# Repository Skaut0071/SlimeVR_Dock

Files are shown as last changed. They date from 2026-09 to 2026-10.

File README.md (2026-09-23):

# SlimeVR\_Dock

Continuation of the tracker project: https://github.com/Skaut0071/SlimeVR_Tracker

This repository contains a smart (overengineered) charging dock station for my previously designed SlimeVR FBT trackers.

The dock is built around an ESP32-C3, which controls the charging system and provides protection logic for connected trackers if a fault condition occurs.

## Features

* 8 USB-C charging ports (J2-J9), arranged as 4 dual-port channels
* Powered from a single USB-C PD input (20V / 3A, negotiated by a CH224K), stepped down to 5V (up to 8.5A) for the ports
* Per-port voltage/current monitoring with an INA226 (8x) over I2C
* Overcurrent protection and per-channel enable/fault handling with an AP22652 load switch (4x)
* Temperature/humidity monitoring (BME280 module on the I2C header)
* 4-pin PWM fan header with tachometer input, driven by the ESP32-C3
* Audible error alerts through an on-board buzzer
* Wireless connectivity over Wi-Fi

## Hardware overview

| Block | Main parts | Notes |
| --- | --- | --- |
| MCU | ESP32-C3-WROOM-02 (U1) | Controls charging, reads monitors, handles faults |
| Power input | USB-C receptacle (J1\_MainPW1), CH224K (U2), NDT452AP (Q1) | Requests 20V from a PD source |
| 5V step-down | TPS548A20 (U4), 2.2uH inductor (L1) | 20V to 5V, 8.5A |
| 3V3 regulator | XC6220B331MR (U3) | Powers the ESP32-C3 and logic |
| Charging channels (x4) | 2x USB-C, 2x INA226, AP22652 load switch, BC857 | Each channel serves two ports; see schematic sheet below |
| I/O expansion | 2x 74HC165 (U17, U18), 74HC595 (U19) | Shift registers for reading channel status and sending control signals |
| Headers | Control, Monitor, Prog (3-pin), Temp (4-pin), Fan (4-pin) | Dev/debug access, sensor and fan connectors |
| Buzzer | BZ1 | Error alerts |

The board is a 2-layer, 1.6mm PCB, roughly 100 x 78 mm (JLCPCB gerbers included).

## Schematic structure

The design is hierarchical (KiCad):

| Sheet | File | Description |
| --- | --- | --- |
| Root - SlimeVR Dock (rev 3.1) | `Board/SlimeVR_Dock.kicad_sch` | MCU, PD input, 3V3 regulator, shift registers, connectors, buzzer |
| 20V to 5V 8.5A Stepdown (rev 2.1) | `Board/StepDown.kicad_sch` | TPS548A20 buck converter |
| Dual USB-C charger monitoring (rev 1.8) | `Board/DUSBSS.kicad_sch` | Instantiated 4x; load switch, protection and detection for a pair of ports |
| Overcurrent protection (rev 1.2) | `Board/USB-C.kicad_sch` | USB-C connector with INA226 current measurement, instantiated 2x per channel |

The PCB is currently at rev 5 (`Board/SlimeVR_Dock.kicad_pcb`).

## Firmware flashing note

To flash new firmware versions, you must use the internal programming pins (`Prog` header).
Or in future, firmware flashing over web interface of the device.

USB-C cannot be used for flashing in this design, because the same USB connection is used to power the board.

## Repository layout

* `Board/` - KiCad project (schematics, PCB, custom footprints in `Library.pretty`)
* `Gerb/` - Gerber/fabrication files for JLCPCB
* `PDF/` - PDF schematic, BOM (CSV) and interactive BOM
* `3D/` - 3D model exports

## Interactive BOM

* [Interactive BOM](https://skaut0071.github.io/SlimeVR_Dock/PDF/ibom.html)

## PDF Schematic

* [PDF Schematic](https://skaut0071.github.io/SlimeVR_Dock/PDF/SlimeVR_Dock.pdf)

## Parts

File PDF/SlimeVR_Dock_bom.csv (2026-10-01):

Reference | Qty | Value | Footprint | # | LCSC
C27 | 1 | 470pF | Capacitor_SMD:C_0805_2012Metric | 1 | C1743
C11,C13 | 2 | 1nF | Capacitor_SMD:C_0603_1608Metric | 2 | alr C100040
C42 | 1 | 2.2nF | Capacitor_SMD:C_0402_1005Metric | 3 | C1531
C14,C15,C16,C17,C18,C19,C20,C21,C28,C32,C33,C34,C35,C36,C37,C38,C43,C44,C45,C46 | 20 | 100nF | Capacitor_SMD:C_0603_1608Metric | 4 | alr C6119867
C39,C41 | 2 | 100nF | Capacitor_SMD:C_0805_2012Metric | 5 | alr C49678
C1,C40,C47 | 3 | 1uF | Capacitor_SMD:C_0603_1608Metric | 6 | alr C15849
L1 | 1 | 2.2uH | Library:L_Coilank_APS0730 | 7 | C49261221
C29 | 1 | 4.7uF | Capacitor_SMD:C_0805_2012Metric | 8 | alr C98192
C2,C3,C4,C5,C6,C7,C8,C9,C10,C12 | 10 | 10uF | Capacitor_SMD:C_0603_1608Metric | 9 | alr C19702
C22,C23,C30 | 3 | 10uF | Capacitor_SMD:C_1210_3225Metric | 10 | alr C47117451
C24,C25,C26,C31 | 4 | 47uF | Capacitor_SMD:C_0805_2012Metric | 11 | alr C16780
R25,R26,R27,R28,R29,R30,R31,R32 | 8 | 50m | Resistor_SMD:R_0805_2012Metric | 12 | C42389461
R55 | 1 | 2R2 | Resistor_SMD:R_0603_1608Metric | 13 | C2907006
R54 | 1 | 3R | Resistor_SMD:R_0805_2012Metric | 14 | C17660
D2 | 1 | 10V | Diode_SMD:D_SOD-123 | 15 | alr C47117498
R1 | 1 | 1k | Resistor_SMD:R_2010_5025Metric | 16 | C2974087
R33 | 1 | 1k | Resistor_SMD:R_0603_1608Metric | 17 | alr C22548
R23,R24 | 2 | 4.7k | Resistor_SMD:R_0603_1608Metric | 18 | alr C99782
R2,R3,R4,R5,R7,R8,R10,R11,R13,R14,R16,R17,R18,R19,R20,R21,R22,R35,R38,R42,R43,R44,R45,R46,R47,R48,R49,R51,R52,R53,R57,R58,R59,R60,R61,R62 | 36 | 10k | Resistor_SMD:R_0603_1608Metric | 19 | alr C98220
R6,R9,R12,R15 | 4 | 13k | Resistor_SMD:R_0603_1608Metric | 20 | C54920854
R36 | 1 | 20k | Resistor_SMD:R_0603_1608Metric | 21 | C2907011
R39 | 1 | 36k | Resistor_SMD:R_0603_1608Metric | 22 | C54531400
R34,R37,R41 | 3 | 75k | Resistor_SMD:R_0603_1608Metric | 23 | alr C2907067
R56 | 1 | 100k | Resistor_SMD:R_0603_1608Metric | 24 | alr C14675
R40 | 1 | 240k | Resistor_SMD:R_0603_1608Metric | 25 | alr C4197
D1 | 1 | 1N4007WS | Diode_SMD:D_SOD-323 | 26 | alr C7473299
U17,U18 | 2 | 74HC165 | Package_SO:SOIC-16_3.9x9.9mm_P1.27mm | 27 | alr C5613
U19 | 1 | 74HC595 | Package_SO:SOIC-16_3.9x9.9mm_P1.27mm | 28 | alr C5947
U5,U8,U11,U14 | 4 | AP22652W6-7 | Library:SOIC_52W6-7_DIO | 29 | alr C2158038
Q6 | 1 | BC817 | Package_TO_SOT_SMD:SOT-23 | 30 | alr C39828
Q2,Q3,Q4,Q5 | 4 | BC857 | Package_TO_SOT_SMD:SOT-23 | 31 | alr C111644
BZ1 | 1 | Buzzer | Buzzer_Beeper:Buzzer_12x9.5RM7.6 | 32 | alr - Any passive buzzer
U2 | 1 | CH224K | Package_SO:SSOP-10-1EP_3.9x4.9mm_P1mm_EP2.1x3.3mm | 33 | alr C970725
J1_Control1,J1_Monitor1,J1_Prog1 | 3 | Conn_01x03_Pin | Connector_PinHeader_2.54mm:PinHeader_1x03_P2.54mm_Vertical | 34 | x - Only holes
J1Fan1 | 1 | Conn_01x04_Pin | Connector:FanPinHeader_1x04_P2.54mm_Vertical | 35 | alr C240840
J1Temp1 | 1 | Conn_01x04_Pin | Connector_PinHeader_2.54mm:PinHeader_1x04_P2.54mm_Vertical | 36 | x - Only holes
U1 | 1 | ESP32-C3-WROOM-02 | RF_Module:ESP32-C3-WROOM-02 | 37 | C2934560
U6,U7,U9,U10,U12,U13,U15,U16 | 8 | INA226 | Package_SO:VSSOP-10_3x3mm_P0.5mm | 38 | alr C49851
Q1 | 1 | NDT452AP | Package_TO_SOT_SMD:SOT-223 | 39 | alr C274614
U4 | 1 | TPS548A20RVER | Library:RVE0028A | 40 | alr C468255
J1_MainPW1 | 1 | USB_C_Receptacle_USB2.0_16P | Connector_USB:USB_C_Receptacle_GCT_USB4105-xx-A_16P_TopMnt_Horizontal | 41 | alr C5178539
J2,J3,J4,J5,J6,J7,J8,J9 | 8 | USB_C_Receptacle_USB2.0_16P | Library:YTC-TC16S-128 | 42 | alr C2927282
U3 | 1 | XC6220B331MR | Package_TO_SOT_SMD:SOT-23-5 | 43 | alr C86534

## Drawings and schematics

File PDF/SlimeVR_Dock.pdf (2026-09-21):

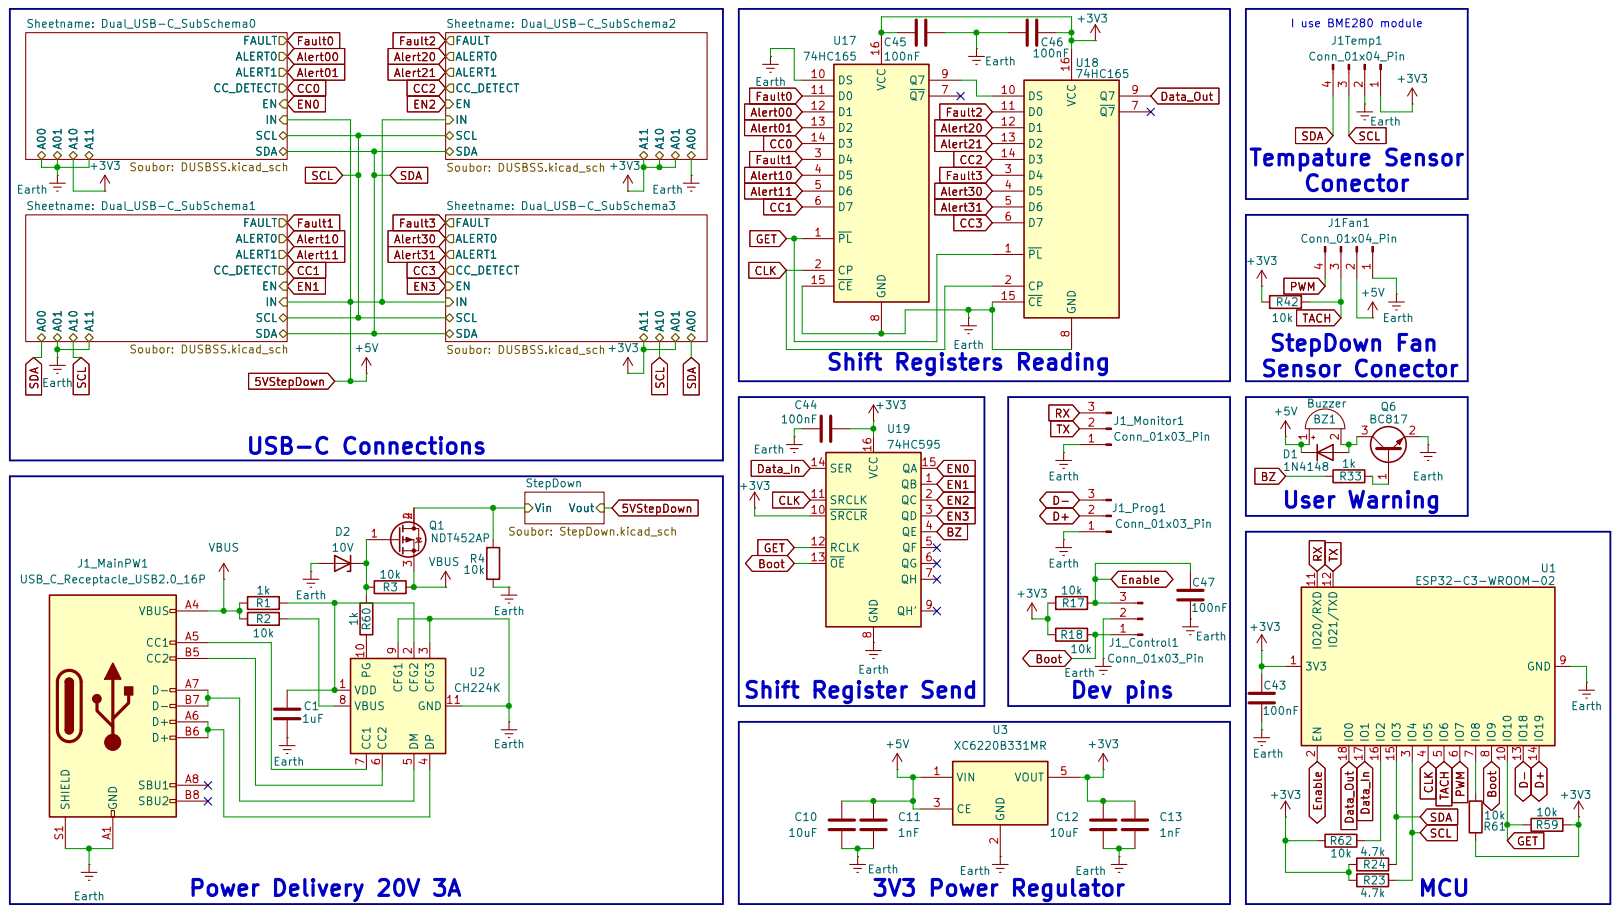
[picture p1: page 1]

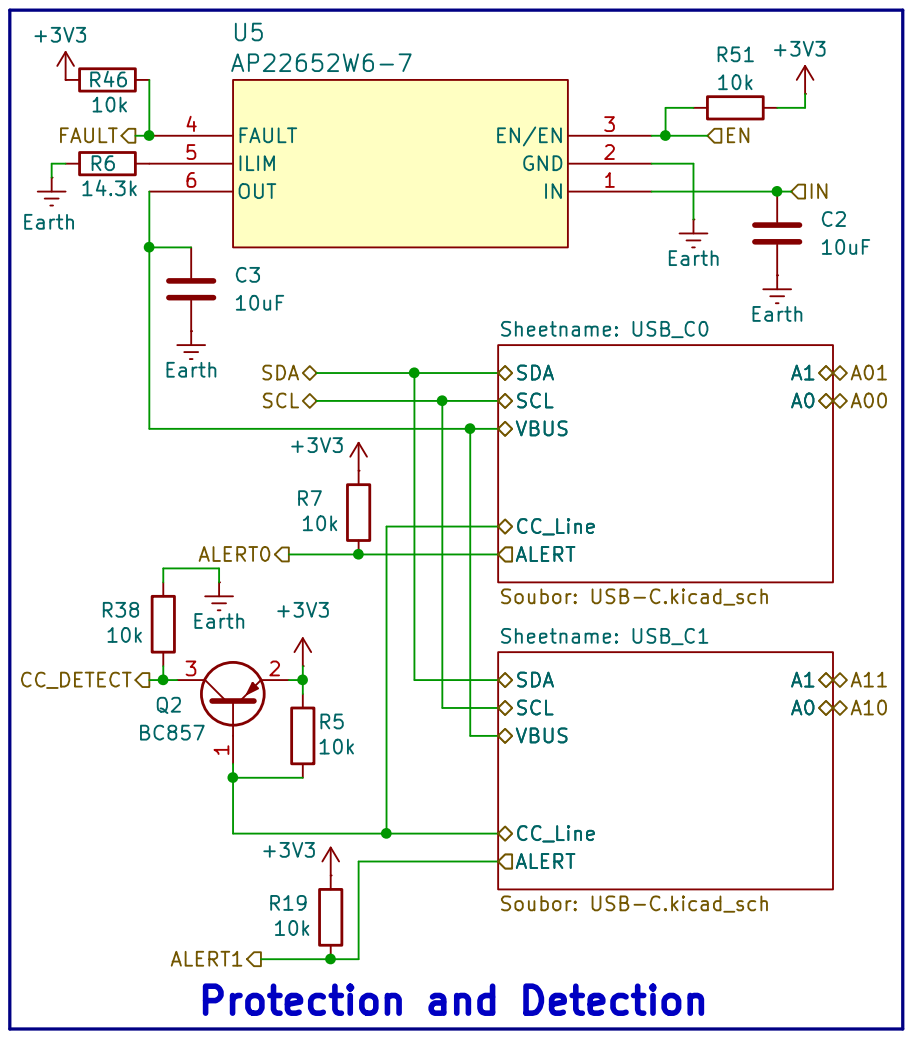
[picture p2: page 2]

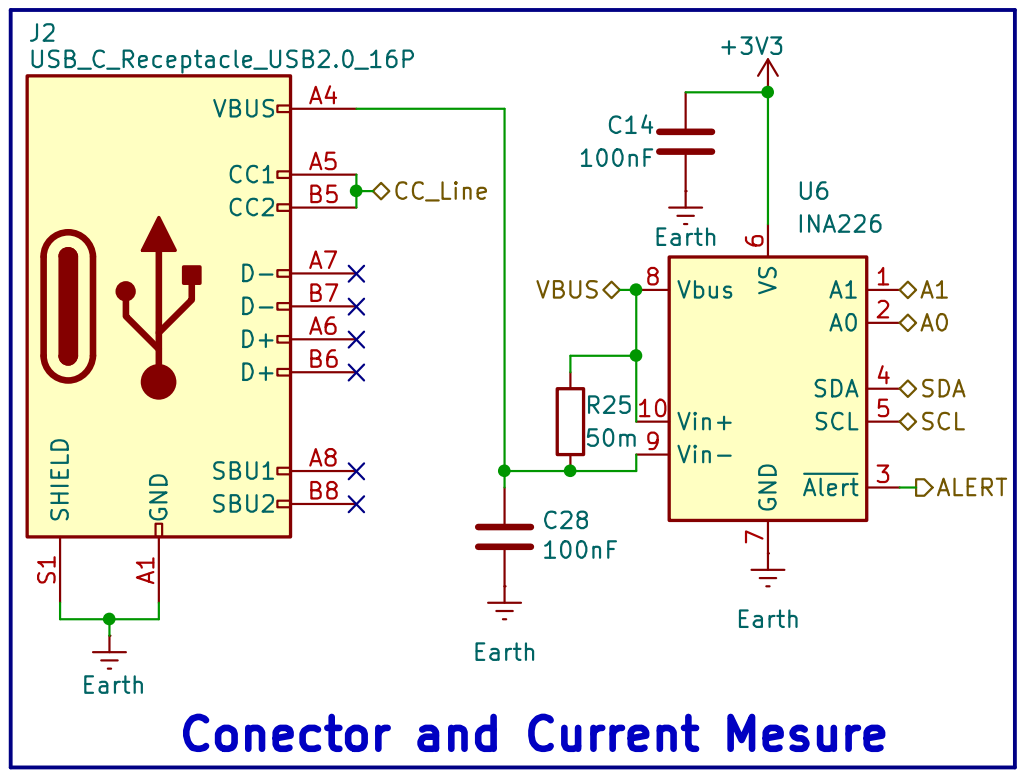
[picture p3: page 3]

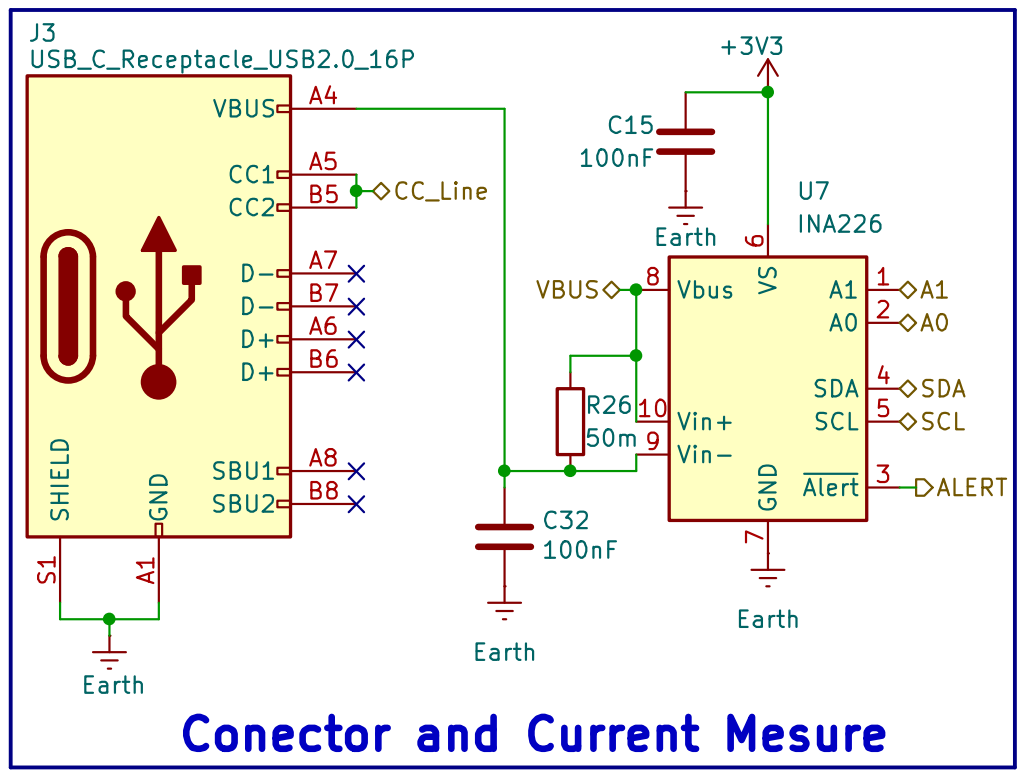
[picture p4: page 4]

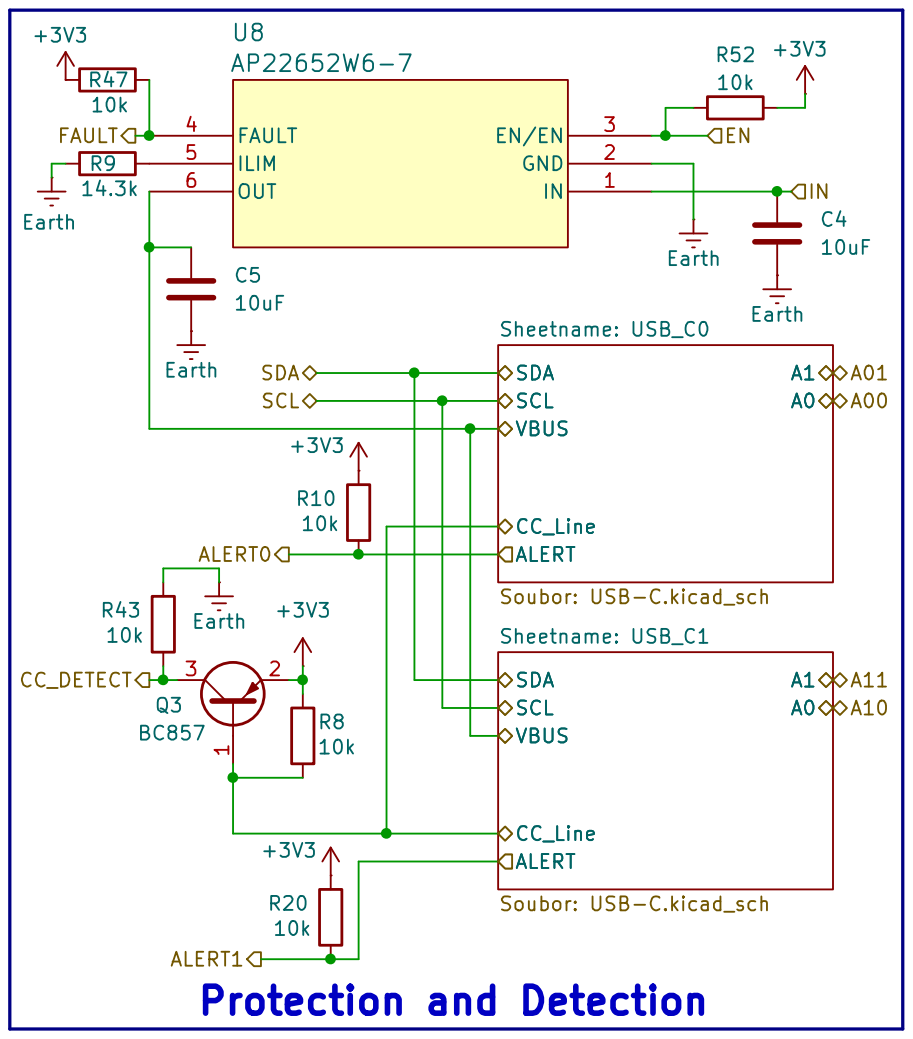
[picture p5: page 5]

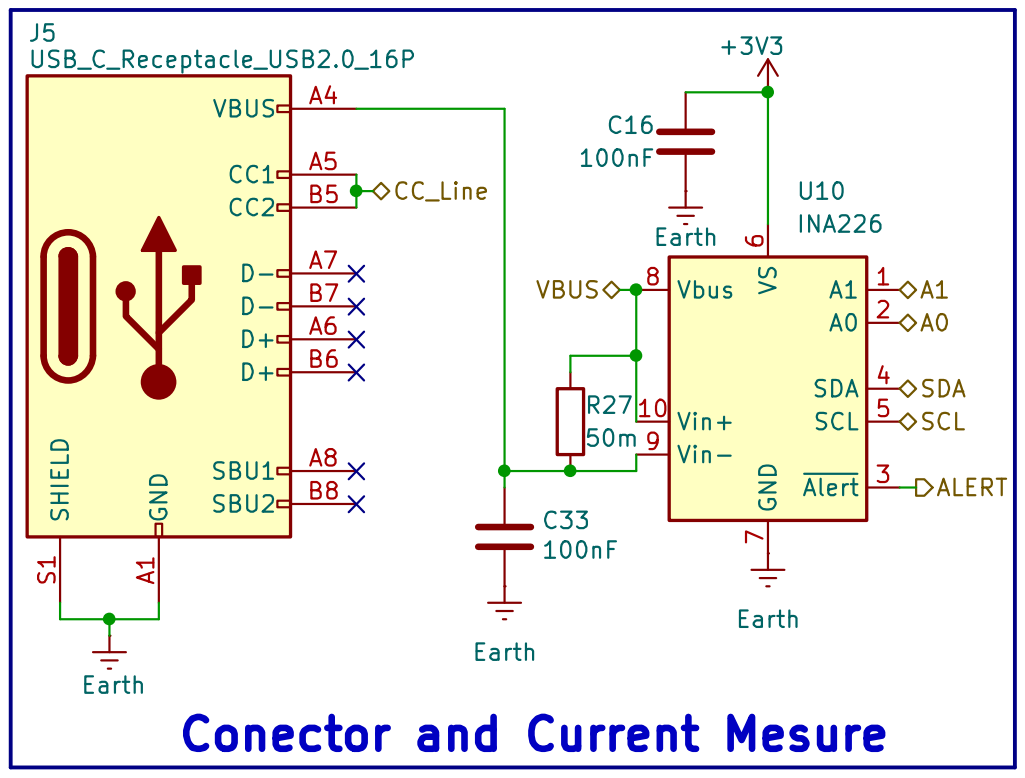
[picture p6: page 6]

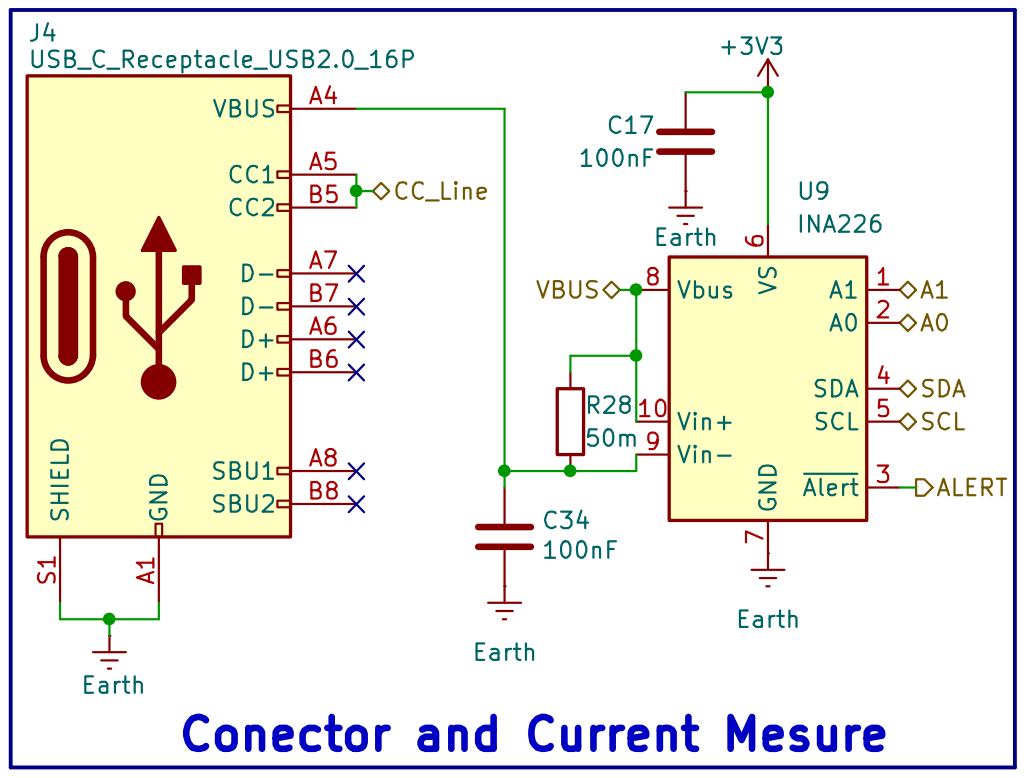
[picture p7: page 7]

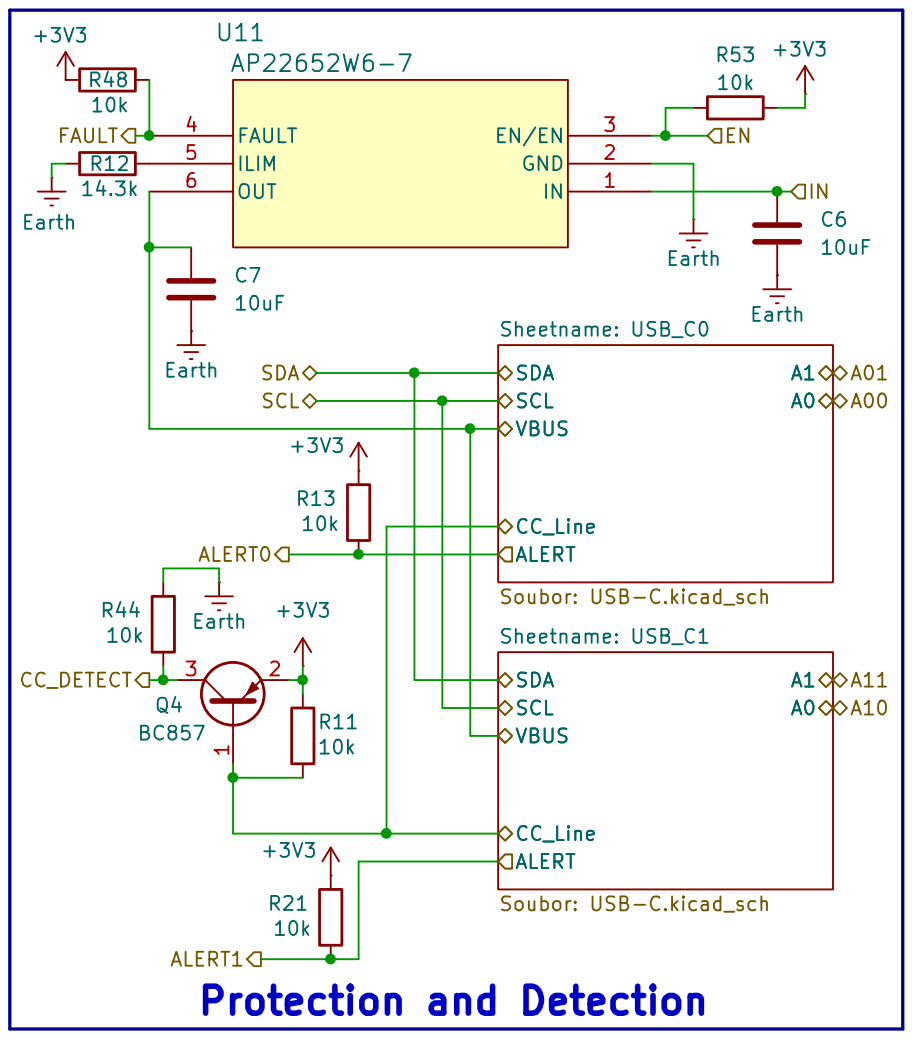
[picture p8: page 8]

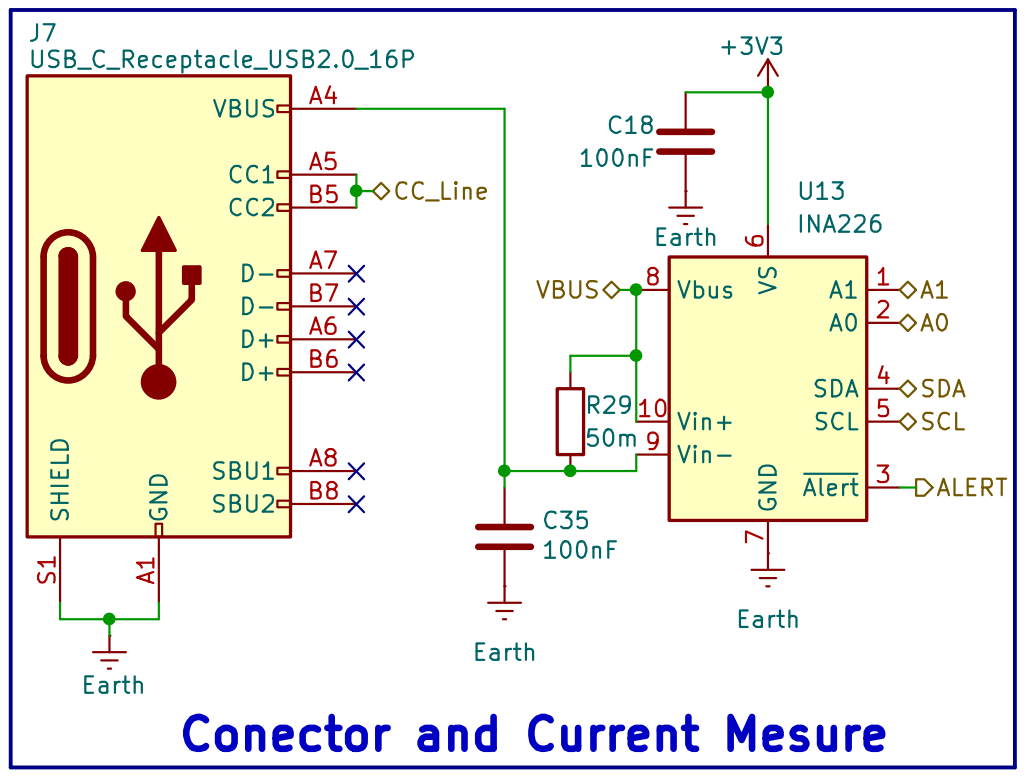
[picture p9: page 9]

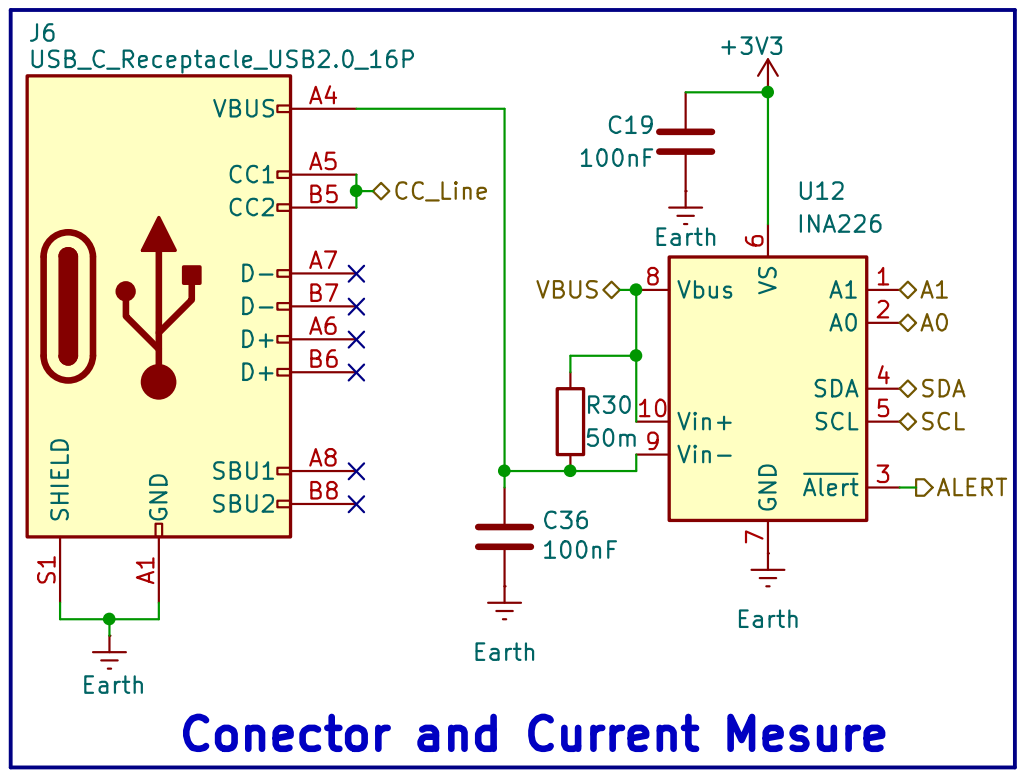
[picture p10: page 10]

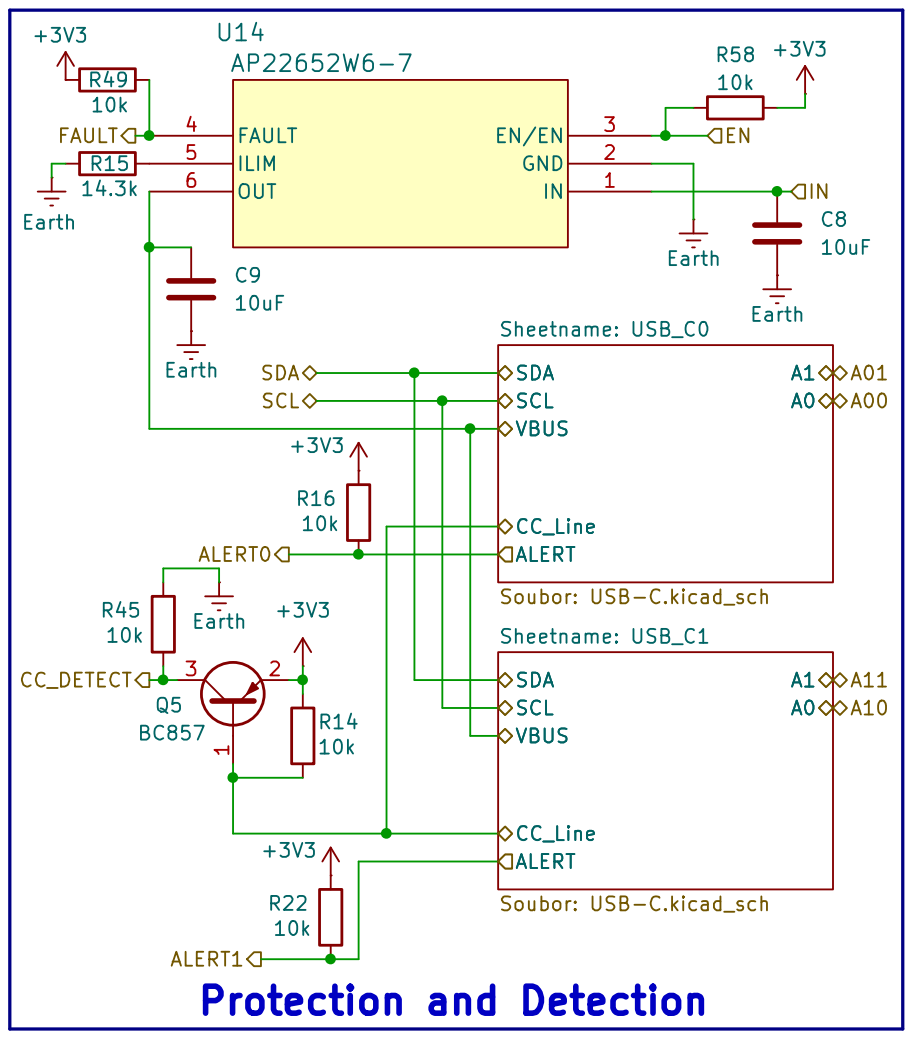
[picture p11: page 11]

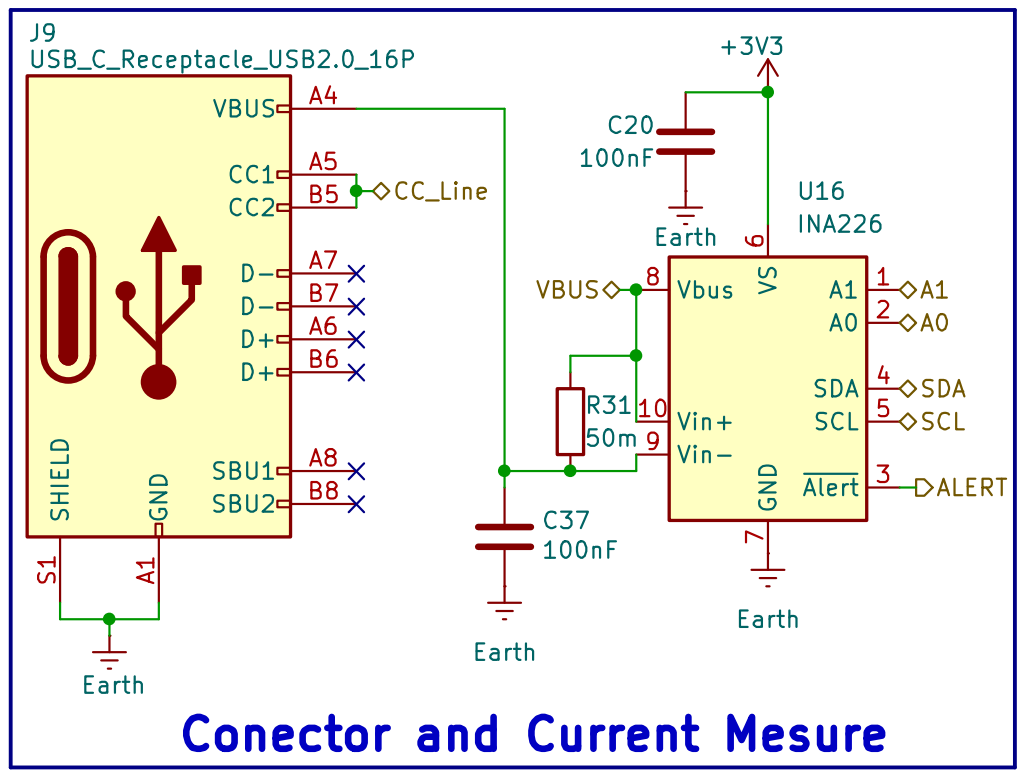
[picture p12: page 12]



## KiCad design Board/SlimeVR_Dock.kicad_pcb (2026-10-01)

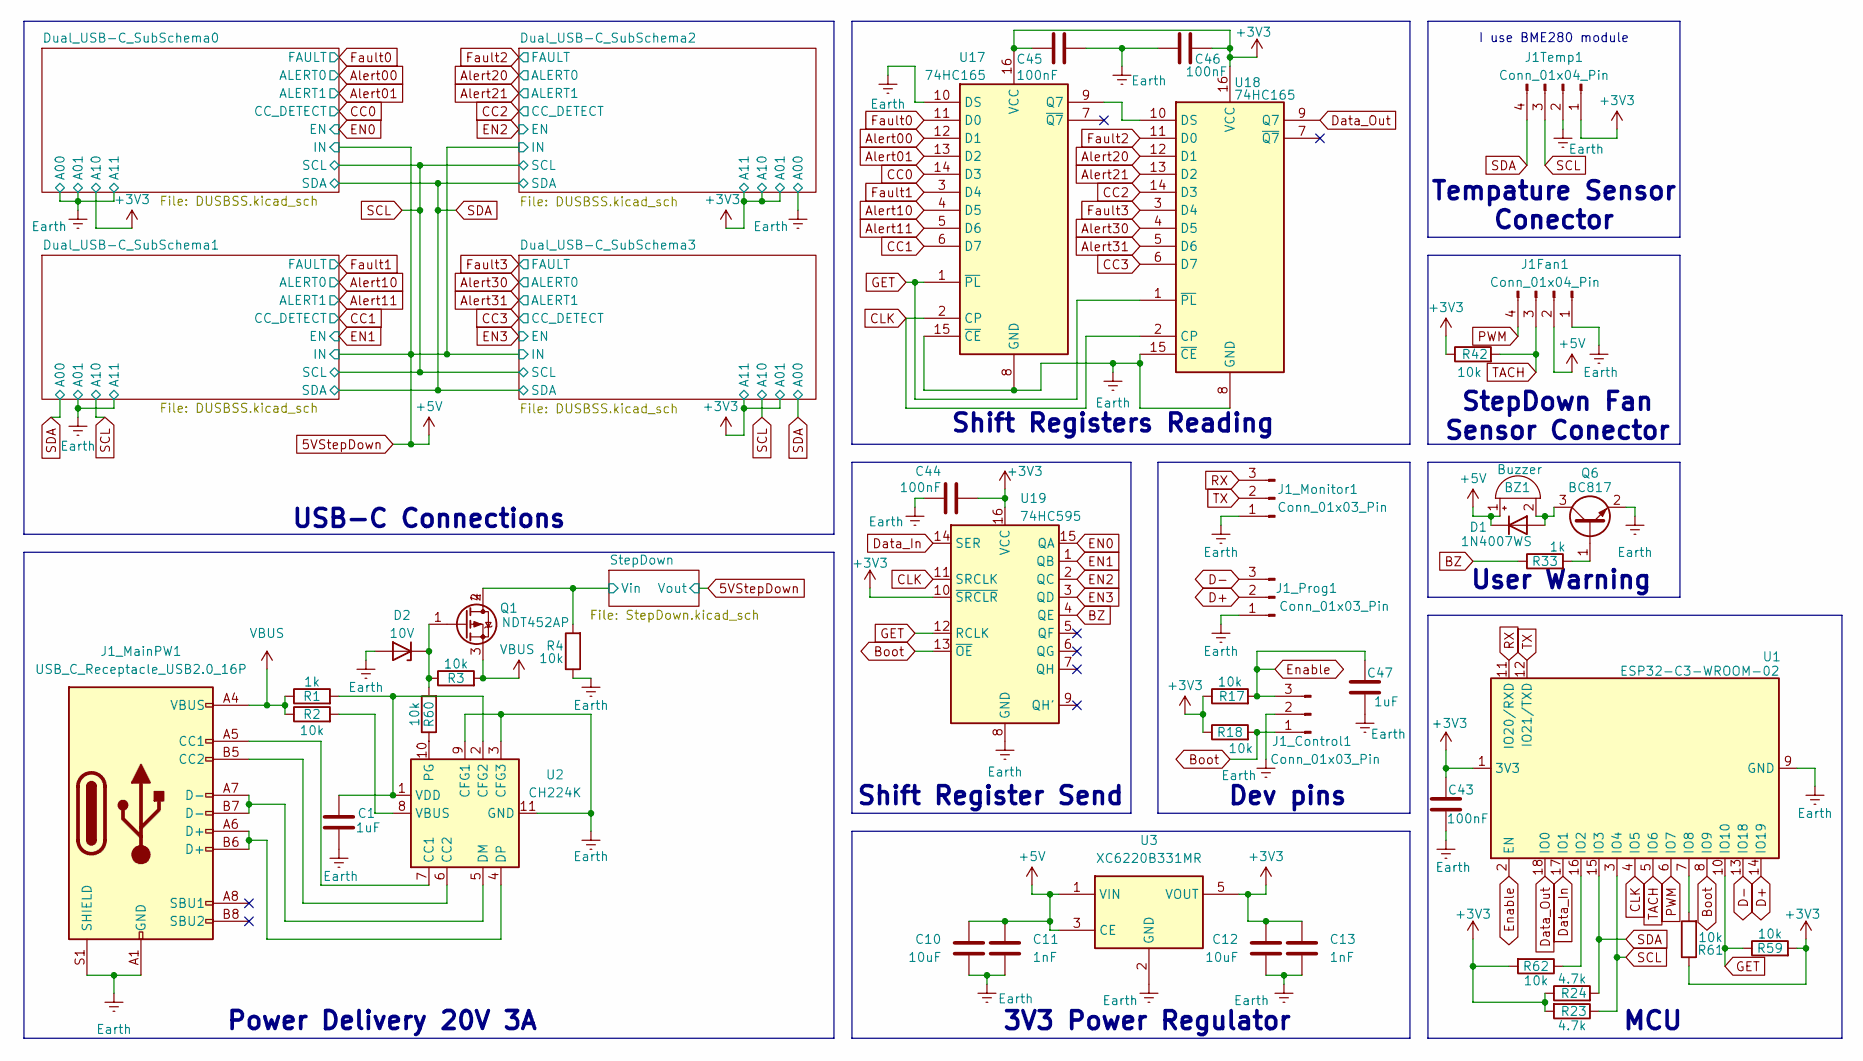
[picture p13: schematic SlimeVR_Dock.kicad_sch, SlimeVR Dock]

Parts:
BZ1: Buzzer; Buzzer_12x9.5RM7.6; LCSC alr - Any passive buzzer
C1, C47: 1uF; C_0603_1608Metric; LCSC C15849
C10, C12: 10uF; C_0603_1608Metric; LCSC alr C19702
C11, C13: 1nF; C_0603_1608Metric; LCSC alr C100040
C43, C44, C45, C46: 100nF; C_0603_1608Metric; LCSC alr C6119867
D1: 1N4007WS; D_SOD-323; LCSC alr C7473299
D2: 10V; D_SOD-123; LCSC alr C47117498
J1Fan1: Conn_01x04_Pin; FanPinHeader_1x04_P2.54mm_Vertical; LCSC alr C240840
J1Temp1: Conn_01x04_Pin; PinHeader_1x04_P2.54mm_Vertical; LCSC x - Only holes
J1_Control1, J1_Monitor1, J1_Prog1: Conn_01x03_Pin; PinHeader_1x03_P2.54mm_Vertical; LCSC x - Only holes
J1_MainPW1: USB_C_Receptacle_USB2.0_16P; USB_C_Receptacle_GCT_USB4105-xx-A_16P_TopMnt_Horizontal; LCSC alr C5178539
Q1: NDT452AP; SOT-223; LCSC alr C274614
Q6: BC817; SOT-23; LCSC alr C39828
R1: 1k; R_2010_5025Metric; LCSC C2974087
R2, R3, R4, R17, R18, R42, R59, R60, R61, R62: 10k; R_0603_1608Metric; LCSC alr C98220
R23, R24: 4.7k; R_0603_1608Metric; LCSC alr C99782
R33: 1k; R_0603_1608Metric; LCSC alr C22548
U1: ESP32-C3-WROOM-02; LCSC C2934560
U2: CH224K; SSOP-10-1EP_3.9x4.9mm_P1mm_EP2.1x3.3mm; LCSC alr C970725
U3: XC6220B331MR; SOT-23-5; LCSC alr C86534
U17, U18: 74HC165; SOIC-16_3.9x9.9mm_P1.27mm; LCSC alr C5613
U19: 74HC595; SOIC-16_3.9x9.9mm_P1.27mm; LCSC alr C5947

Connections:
5VStepDown: BZ1.1 (+), C10.1, C11.1, D1.1 (K), J1Fan1.2, U3.1 (VIN), U3.3 (CE); also elsewhere on the board
+3V3: C12.1, C13.1, C43.1, C44.2, C45.2, C46.1, J1Temp1.1, R17.1, R18.1, R23.2, R24.1, R42.1, R59.2, R61.1, R62.2, U1.1 (3V3), U3.5 (VOUT), U17.16 (VCC), U18.16 (VCC), U19.10 (~SRCLR), U19.16 (VCC); also elsewhere on the board
/StepDown/Vin: Q1.2 (D), Q1.4 (D), R4.2; also elsewhere on the board
Alert00: U17.12 (D1); also elsewhere on the board
Alert01: U17.13 (D2); also elsewhere on the board
Alert10: U17.4 (D5); also elsewhere on the board
Alert11: U17.5 (D6); also elsewhere on the board
Alert20: U18.12 (D1); also elsewhere on the board
Alert21: U18.13 (D2); also elsewhere on the board
Alert30: U18.4 (D5); also elsewhere on the board
Alert31: U18.5 (D6); also elsewhere on the board
BZ: R33.1, U19.4 (QE)
Boot: J1_Control1.1, R18.2, U1.8 (IO9), U19.13 (~OE)
CC0: U17.14 (D3); also elsewhere on the board
CC1: U17.6 (D7); also elsewhere on the board
CC2: U18.14 (D3); also elsewhere on the board
CC3: U18.6 (D7); also elsewhere on the board
CLK: U1.4 (IO5), U17.2 (CP), U18.2 (CP), U19.11 (SRCLK)
D+: J1_Prog1.2, U1.14 (IO19)
D-: J1_Prog1.3, U1.13 (IO18)
Data_In: U1.17 (IO1), U19.14 (SER)
Data_Out: U1.18 (IO0), U18.9 (Q7)
EN0: U19.15 (QA); also elsewhere on the board
EN1: U19.1 (QB); also elsewhere on the board
EN2: U19.2 (QC); also elsewhere on the board
EN3: U19.3 (QD); also elsewhere on the board
Earth: C1.1, C10.2, C11.2, C12.2, C13.2, C43.2, C44.1, C45.1, C46.2, C47.2, D2.2 (A), J1Fan1.1, J1Temp1.2, J1_Control1.2, J1_MainPW1.A1 (GND), J1_MainPW1.A12 (GND), J1_MainPW1.B1 (GND), J1_MainPW1.B12 (GND), J1_MainPW1.S1 (SHIELD), J1_Monitor1.1, J1_Prog1.1, Q6.2 (E), R4.1, U1.9 (GND), U1.19 (GND), U2.3 (CFG3), U2.9 (CFG1), U2.11 (GND), U3.2 (GND), U17.8 (GND), U17.10 (DS), U17.15 (~CE), U18.8 (GND), U18.15 (~CE), U19.8 (GND); also elsewhere on the board
Enable: C47.1, J1_Control1.3, R17.2, U1.2 (EN)
Fault0: U17.11 (D0); also elsewhere on the board
Fault1: U17.3 (D4); also elsewhere on the board
Fault2: U18.11 (D0); also elsewhere on the board
Fault3: U18.3 (D4); also elsewhere on the board
GET: R59.1, U1.10 (IO10), U17.1 (~PL), U18.1 (~PL), U19.12 (RCLK)
unnamed: BZ1.2 (-), D1.2 (A), Q6.3 (C)
unnamed: D2.1 (K), Q1.1 (G), R3.1, R60.2
unnamed: J1_MainPW1.A5 (CC1), U2.7 (CC1)
unnamed: J1_MainPW1.B5 (CC2), U2.6 (CC2)
unnamed: Q6.1 (B), R33.2
unnamed: R62.1, U1.16 (IO2)
unnamed: R61.2, U1.7 (IO8)
unnamed: C1.2, R1.2, U2.1 (VDD), U2.2 (CFG2)
unnamed: J1_MainPW1.A7 (D-), J1_MainPW1.B7 (D-), U2.5 (DM)
unnamed: J1_MainPW1.A6 (D+), J1_MainPW1.B6 (D+), U2.4 (DP)
unnamed: R60.1, U2.10 (PG)
unnamed: R2.2, U2.8 (VBUS)
unnamed: U17.9 (Q7), U18.10 (DS)
PWM: J1Fan1.4, U1.6 (IO7)
RX: J1_Monitor1.3, U1.11 (IO20/RXD)
SCL: J1Temp1.3, R23.1, U1.3 (IO4); also elsewhere on the board
SDA: J1Temp1.4, R24.2, U1.15 (IO3); also elsewhere on the board
TACH: J1Fan1.3, R42.2, U1.5 (IO6)
TX: J1_Monitor1.2, U1.12 (IO21/TXD)
VBUS: J1_MainPW1.A4 (VBUS), J1_MainPW1.A9 (VBUS), J1_MainPW1.B4 (VBUS), J1_MainPW1.B9 (VBUS), Q1.3 (S), R1.1, R2.1, R3.2

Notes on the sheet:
User Warning
MCU
Tempature Sensor Conector
Shift Registers Reading
3V3 Power Regulator
Power Delivery 20V 3A
I use BME280 module
Dev pins
USB-C Connections
StepDown Fan Sensor Conector
Shift Register Send

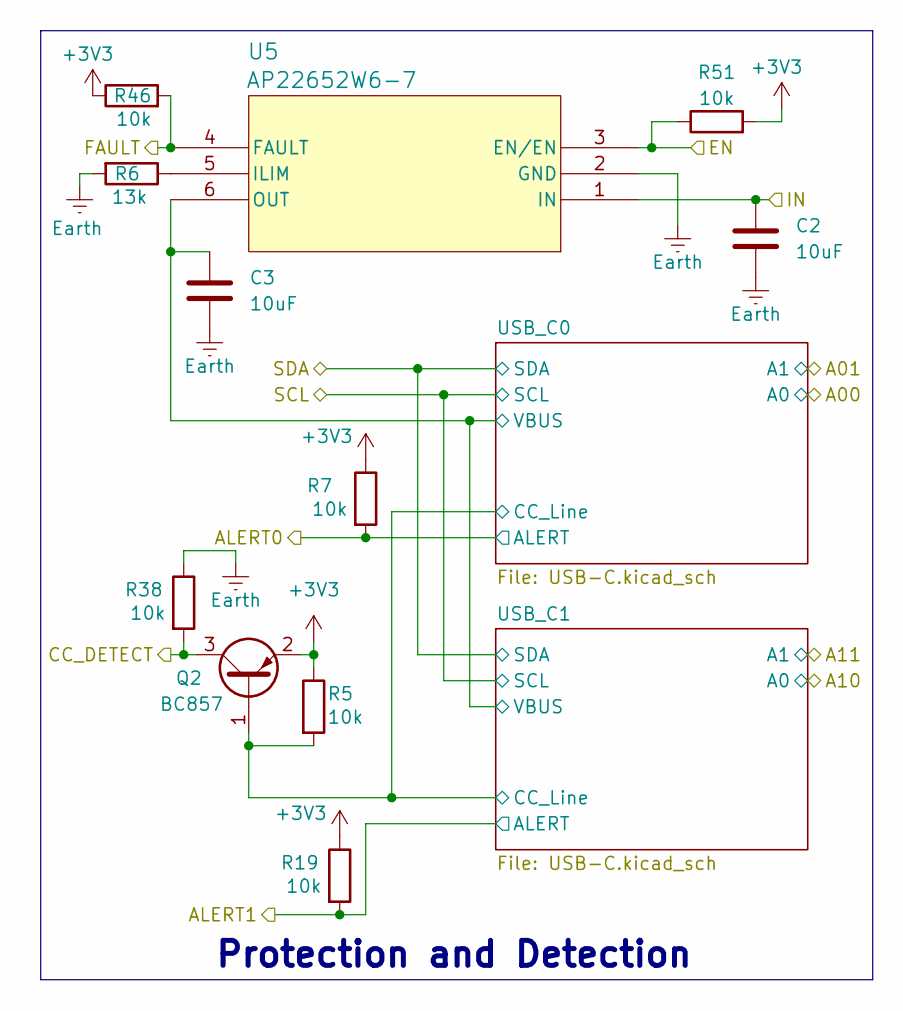
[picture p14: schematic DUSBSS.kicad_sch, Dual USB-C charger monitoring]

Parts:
C2, C3: 10uF; C_0603_1608Metric; LCSC alr C19702
Q2: BC857; SOT-23; LCSC alr C111644
R5, R7, R19, R38, R46, R51: 10k; R_0603_1608Metric; LCSC alr C98220
R6: 13k; R_0603_1608Metric; LCSC C54920854
U5: AP22652W6-7; SOIC_52W6-7_DIO; LCSC alr C2158038

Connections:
5VStepDown: C2.1, U5.1 (IN); also elsewhere on the board
+3V3: Q2.2 (E), R5.1, R7.1, R19.1, R46.1, R51.2; also elsewhere on the board
/Dual_USB-C_SubSchema0/USB_C0/CC_Line: Q2.1 (B), R5.2; also elsewhere on the board
/Dual_USB-C_SubSchema0/USB_C0/VBUS: C3.1, U5.6 (OUT); also elsewhere on the board
Alert00: R7.2; also elsewhere on the board
Alert01: R19.2; also elsewhere on the board
CC0: Q2.3 (C), R38.2; also elsewhere on the board
EN0: R51.1, U5.3 (EN/EN); also elsewhere on the board
Earth: C2.2, C3.2, R6.2, R38.1, U5.2 (GND); also elsewhere on the board
Fault0: R46.2, U5.4 (FAULT); also elsewhere on the board
unnamed: R6.1, U5.5 (ILIM)

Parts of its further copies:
C4, C5, C6, C7, C8, C9: 10uF; C_0603_1608Metric; LCSC alr C19702
Q3, Q4, Q5: BC857; SOT-23; LCSC alr C111644
R8, R10, R11, R13, R14, R16, R20, R21, R22, R43, R44, R45, R47, R48, R49, R52, R53, R58: 10k; R_0603_1608Metric; LCSC alr C98220
R9, R12, R15: 13k; R_0603_1608Metric; LCSC C54920854
U8, U11, U14: AP22652W6-7; SOIC_52W6-7_DIO; LCSC alr C2158038

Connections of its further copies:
5VStepDown: C4.1, C6.1, C8.1, U8.1 (IN), U11.1 (IN), U14.1 (IN); also elsewhere on the board
+3V3: Q3.2 (E), Q4.2 (E), Q5.2 (E), R8.1, R10.1, R11.1, R13.1, R14.1, R16.1, R20.1, R21.1, R22.1, R47.1, R48.1, R49.1, R52.2, R53.2, R58.2; also elsewhere on the board
/Dual_USB-C_SubSchema1/USB_C0/CC_Line: Q3.1 (B), R8.2; also elsewhere on the board
/Dual_USB-C_SubSchema1/USB_C0/VBUS: C5.1, U8.6 (OUT); also elsewhere on the board
/Dual_USB-C_SubSchema2/USB_C0/CC_Line: Q4.1 (B), R11.2; also elsewhere on the board
/Dual_USB-C_SubSchema2/USB_C0/VBUS: C7.1, U11.6 (OUT); also elsewhere on the board
/Dual_USB-C_SubSchema3/USB_C0/CC_Line: Q5.1 (B), R14.2; also elsewhere on the board
/Dual_USB-C_SubSchema3/USB_C0/VBUS: C9.1, U14.6 (OUT); also elsewhere on the board
Alert10: R10.2; also elsewhere on the board
Alert11: R20.2; also elsewhere on the board
Alert20: R13.2; also elsewhere on the board
Alert21: R21.2; also elsewhere on the board
Alert30: R16.2; also elsewhere on the board
Alert31: R22.2; also elsewhere on the board
CC1: Q3.3 (C), R43.2; also elsewhere on the board
CC2: Q4.3 (C), R44.2; also elsewhere on the board
CC3: Q5.3 (C), R45.2; also elsewhere on the board
EN1: R52.1, U8.3 (EN/EN); also elsewhere on the board
EN2: R53.1, U11.3 (EN/EN); also elsewhere on the board
EN3: R58.1, U14.3 (EN/EN); also elsewhere on the board
Earth: C4.2, C5.2, C6.2, C7.2, C8.2, C9.2, R9.2, R12.2, R15.2, R43.1, R44.1, R45.1, U8.2 (GND), U11.2 (GND), U14.2 (GND); also elsewhere on the board
Fault1: R47.2, U8.4 (FAULT); also elsewhere on the board
Fault2: R48.2, U11.4 (FAULT); also elsewhere on the board
Fault3: R49.2, U14.4 (FAULT); also elsewhere on the board
unnamed: R9.1, U8.5 (ILIM)
unnamed: R12.1, U11.5 (ILIM)
unnamed: R15.1, U14.5 (ILIM)

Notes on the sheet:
Protection and Detection

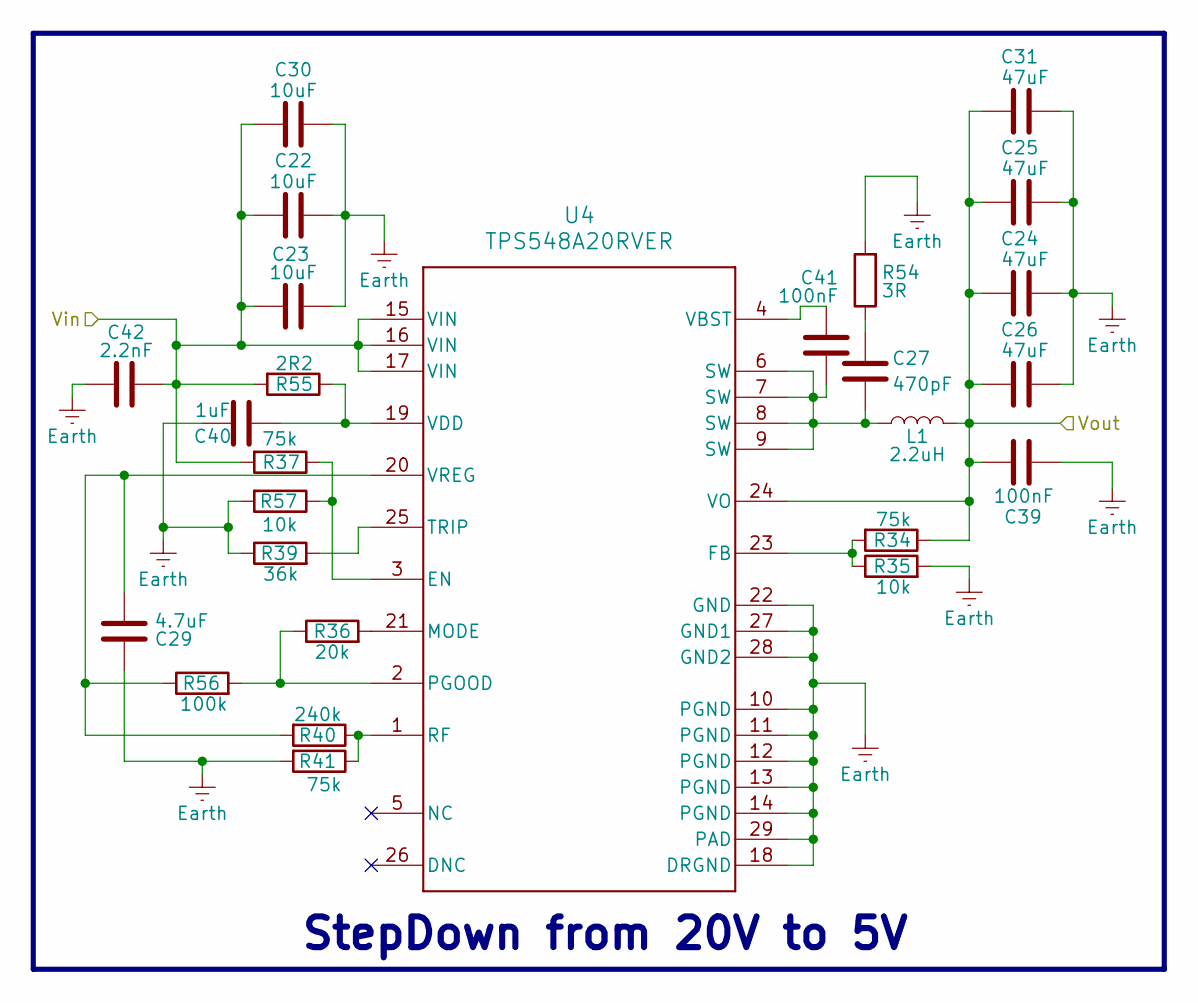
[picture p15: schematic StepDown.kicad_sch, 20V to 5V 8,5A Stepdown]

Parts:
C22, C23, C30: 10uF; C_1210_3225Metric; LCSC alr C47117451
C24, C25, C26, C31: 47uF; C_0805_2012Metric; LCSC alr C16780
C27: 470pF; C_0805_2012Metric; LCSC C1743
C29: 4.7uF; C_0805_2012Metric; LCSC alr C98192
C39, C41: 100nF; C_0805_2012Metric; LCSC alr C49678
C40: 1uF; C_0603_1608Metric; LCSC C15849
C42: 2.2nF; C_0402_1005Metric; LCSC C1531
L1: 2.2uH; L_Coilank_APS0730; LCSC C49261221
R34, R37, R41: 75k; R_0603_1608Metric; LCSC alr C2907067
R35, R57: 10k; R_0603_1608Metric; LCSC alr C98220
R36: 20k; R_0603_1608Metric; LCSC C2907011
R39: 36k; R_0603_1608Metric; LCSC C54531400
R40: 240k; R_0603_1608Metric; LCSC alr C4197
R54: 3R; R_0805_2012Metric; LCSC C17660
R55: 2R2; R_0603_1608Metric; LCSC C2907006
R56: 100k; R_0603_1608Metric; LCSC alr C14675
U4: TPS548A20RVER; RVE0028A; LCSC alr C468255

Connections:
5VStepDown: C24.1, C25.1, C26.1, C31.1, C39.2, L1.2, R34.1, U4.24 (VO); also elsewhere on the board
/StepDown/Vin: C22.1, C23.1, C30.1, C42.1, R37.2, R55.2, U4.15 (VIN), U4.16 (VIN), U4.17 (VIN); also elsewhere on the board
Earth: C22.2, C23.2, C24.2, C25.2, C26.2, C29.1, C30.2, C31.2, C39.1, C40.1, C42.2, R35.2, R39.1, R41.2, R54.2, R57.2, U4.10 (PGND), U4.11 (PGND), U4.12 (PGND), U4.13 (PGND), U4.14 (PGND), U4.18 (DRGND), U4.22 (GND), U4.27 (GND1), U4.28 (GND2), U4.29 (PAD); also elsewhere on the board
unnamed: C27.1, R54.1
unnamed: C27.2, C41.1, L1.1, U4.6 (SW), U4.7 (SW), U4.8 (SW), U4.9 (SW)
unnamed: R37.1, R57.1, U4.3 (EN)
unnamed: R34.2, R35.1, U4.23 (FB)
unnamed: R36.2, U4.21 (MODE)
unnamed: R36.1, R56.2, U4.2 (PGOOD)
unnamed: R40.1, R41.1, U4.1 (RF)
unnamed: R39.2, U4.25 (TRIP)
unnamed: C41.2, U4.4 (VBST)
unnamed: C40.2, R55.1, U4.19 (VDD)
unnamed: C29.2, R40.2, R56.1, U4.20 (VREG)

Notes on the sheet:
StepDown from 20V to 5V

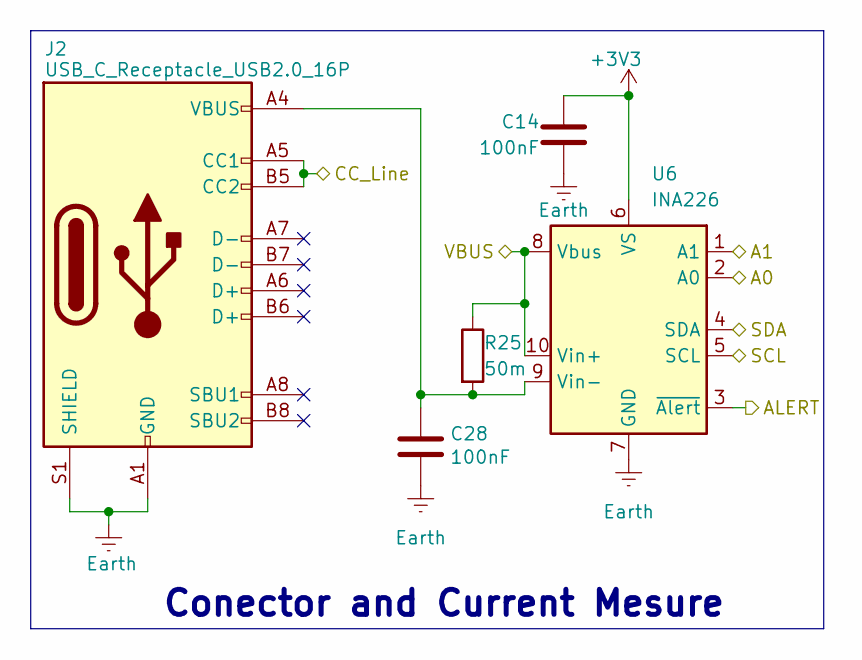
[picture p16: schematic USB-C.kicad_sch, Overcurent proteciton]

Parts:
C14, C28: 100nF; C_0603_1608Metric; LCSC alr C6119867
J2: USB_C_Receptacle_USB2.0_16P; YTC-TC16S-128; LCSC alr C2927282
R25: 50m; R_0805_2012Metric; LCSC C42389461
U6: INA226; VSSOP-10_3x3mm_P0.5mm; LCSC alr C49851

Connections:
+3V3: C14.1, U6.6 (VS); also elsewhere on the board
/Dual_USB-C_SubSchema0/USB_C0/CC_Line: J2.A5 (CC1), J2.B5 (CC2); also elsewhere on the board
/Dual_USB-C_SubSchema0/USB_C0/VBUS: R25.1, U6.8 (Vbus), U6.10 (Vin+); also elsewhere on the board
Alert00: U6.3 (~Alert); also elsewhere on the board
Earth: C14.2, C28.1, J2.A1 (GND), J2.A12 (GND), J2.B1 (GND), J2.B12 (GND), J2.S1 (SHIELD), U6.1 (A1), U6.2 (A0), U6.7 (GND); also elsewhere on the board
unnamed: C28.2, J2.A4 (VBUS), J2.A9 (VBUS), J2.B4 (VBUS), J2.B9 (VBUS), R25.2, U6.9 (Vin-)
SCL: U6.5 (SCL); also elsewhere on the board
SDA: U6.4 (SDA); also elsewhere on the board

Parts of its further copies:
C15, C16, C17, C18, C19, C20, C21, C32, C33, C34, C35, C36, C37, C38: 100nF; C_0603_1608Metric; LCSC alr C6119867
J3, J4, J5, J6, J7, J8, J9: USB_C_Receptacle_USB2.0_16P; YTC-TC16S-128; LCSC alr C2927282
R26, R27, R28, R29, R30, R31, R32: 50m; R_0805_2012Metric; LCSC C42389461
U7, U9, U10, U12, U13, U15, U16: INA226; VSSOP-10_3x3mm_P0.5mm; LCSC alr C49851

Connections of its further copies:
+3V3: C15.1, C16.1, C17.1, C18.1, C19.1, C20.1, C21.1, U7.2 (A0), U7.6 (VS), U9.6 (VS), U10.6 (VS), U12.1 (A1), U12.6 (VS), U13.1 (A1), U13.2 (A0), U13.6 (VS), U15.1 (A1), U15.6 (VS), U16.1 (A1), U16.6 (VS); also elsewhere on the board
/Dual_USB-C_SubSchema0/USB_C0/CC_Line: J3.A5 (CC1), J3.B5 (CC2); also elsewhere on the board
/Dual_USB-C_SubSchema0/USB_C0/VBUS: R26.1, U7.8 (Vbus), U7.10 (Vin+); also elsewhere on the board
/Dual_USB-C_SubSchema1/USB_C0/CC_Line: J4.A5 (CC1), J4.B5 (CC2), J5.A5 (CC1), J5.B5 (CC2); also elsewhere on the board
/Dual_USB-C_SubSchema1/USB_C0/VBUS: R27.1, R28.1, U9.8 (Vbus), U9.10 (Vin+), U10.8 (Vbus), U10.10 (Vin+); also elsewhere on the board
/Dual_USB-C_SubSchema2/USB_C0/CC_Line: J6.A5 (CC1), J6.B5 (CC2), J7.A5 (CC1), J7.B5 (CC2); also elsewhere on the board
/Dual_USB-C_SubSchema2/USB_C0/VBUS: R29.1, R30.1, U12.8 (Vbus), U12.10 (Vin+), U13.8 (Vbus), U13.10 (Vin+); also elsewhere on the board
/Dual_USB-C_SubSchema3/USB_C0/CC_Line: J8.A5 (CC1), J8.B5 (CC2), J9.A5 (CC1), J9.B5 (CC2); also elsewhere on the board
/Dual_USB-C_SubSchema3/USB_C0/VBUS: R31.1, R32.1, U15.8 (Vbus), U15.10 (Vin+), U16.8 (Vbus), U16.10 (Vin+); also elsewhere on the board
Alert01: U7.3 (~Alert); also elsewhere on the board
Alert10: U9.3 (~Alert); also elsewhere on the board
Alert11: U10.3 (~Alert); also elsewhere on the board
Alert20: U12.3 (~Alert); also elsewhere on the board
Alert21: U13.3 (~Alert); also elsewhere on the board
Alert30: U15.3 (~Alert); also elsewhere on the board
Alert31: U16.3 (~Alert); also elsewhere on the board
Earth: C15.2, C16.2, C17.2, C18.2, C19.2, C20.2, C21.2, C32.1, C33.1, C34.1, C35.1, C36.1, C37.1, C38.1, J3.A1 (GND), J3.A12 (GND), J3.B1 (GND), J3.B12 (GND), J3.S1 (SHIELD), J4.A1 (GND), J4.A12 (GND), J4.B1 (GND), J4.B12 (GND), J4.S1 (SHIELD), J5.A1 (GND), J5.A12 (GND), J5.B1 (GND), J5.B12 (GND), J5.S1 (SHIELD), J6.A1 (GND), J6.A12 (GND), J6.B1 (GND), J6.B12 (GND), J6.S1 (SHIELD), J7.A1 (GND), J7.A12 (GND), J7.B1 (GND), J7.B12 (GND), J7.S1 (SHIELD), J8.A1 (GND), J8.A12 (GND), J8.B1 (GND), J8.B12 (GND), J8.S1 (SHIELD), J9.A1 (GND), J9.A12 (GND), J9.B1 (GND), J9.B12 (GND), J9.S1 (SHIELD), U7.1 (A1), U7.7 (GND), U9.1 (A1), U9.7 (GND), U10.1 (A1), U10.7 (GND), U12.2 (A0), U12.7 (GND), U13.7 (GND), U15.7 (GND), U16.7 (GND); also elsewhere on the board
unnamed: C32.2, J3.A4 (VBUS), J3.A9 (VBUS), J3.B4 (VBUS), J3.B9 (VBUS), R26.2, U7.9 (Vin-)
unnamed: C34.2, J4.A4 (VBUS), J4.A9 (VBUS), J4.B4 (VBUS), J4.B9 (VBUS), R28.2, U9.9 (Vin-)
unnamed: C33.2, J5.A4 (VBUS), J5.A9 (VBUS), J5.B4 (VBUS), J5.B9 (VBUS), R27.2, U10.9 (Vin-)
unnamed: C36.2, J6.A4 (VBUS), J6.A9 (VBUS), J6.B4 (VBUS), J6.B9 (VBUS), R30.2, U12.9 (Vin-)
unnamed: C35.2, J7.A4 (VBUS), J7.A9 (VBUS), J7.B4 (VBUS), J7.B9 (VBUS), R29.2, U13.9 (Vin-)
unnamed: C38.2, J8.A4 (VBUS), J8.A9 (VBUS), J8.B4 (VBUS), J8.B9 (VBUS), R32.2, U15.9 (Vin-)
unnamed: C37.2, J9.A4 (VBUS), J9.A9 (VBUS), J9.B4 (VBUS), J9.B9 (VBUS), R31.2, U16.9 (Vin-)
SCL: U7.5 (SCL), U9.5 (SCL), U10.2 (A0), U10.5 (SCL), U12.5 (SCL), U13.5 (SCL), U15.5 (SCL), U16.2 (A0), U16.5 (SCL); also elsewhere on the board
SDA: U7.4 (SDA), U9.2 (A0), U9.4 (SDA), U10.4 (SDA), U12.4 (SDA), U13.4 (SDA), U15.2 (A0), U15.4 (SDA), U16.4 (SDA); also elsewhere on the board

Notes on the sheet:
Conector and Current Mesure

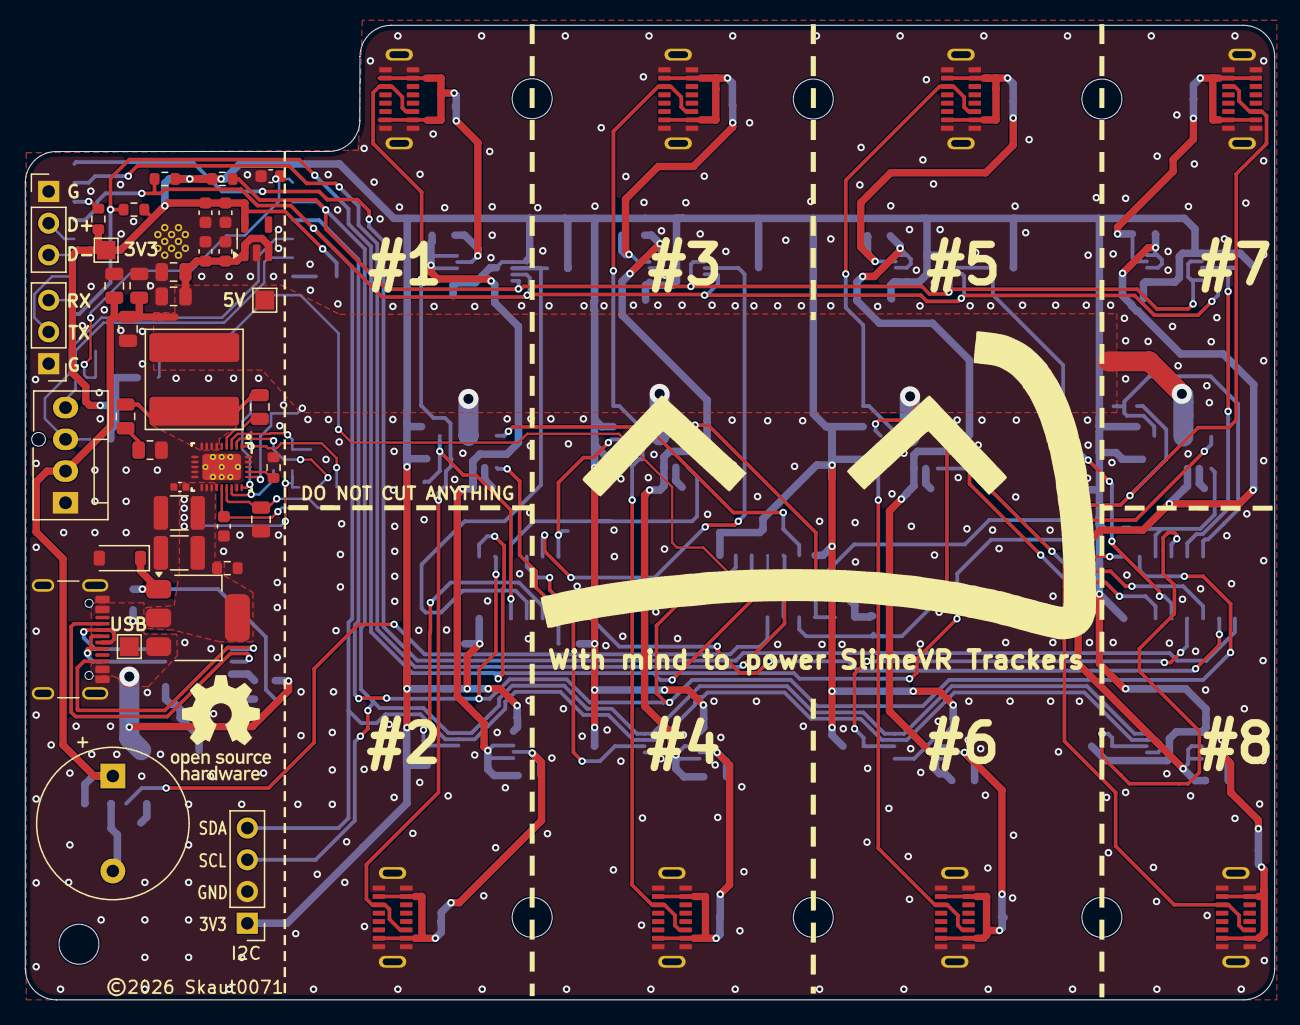
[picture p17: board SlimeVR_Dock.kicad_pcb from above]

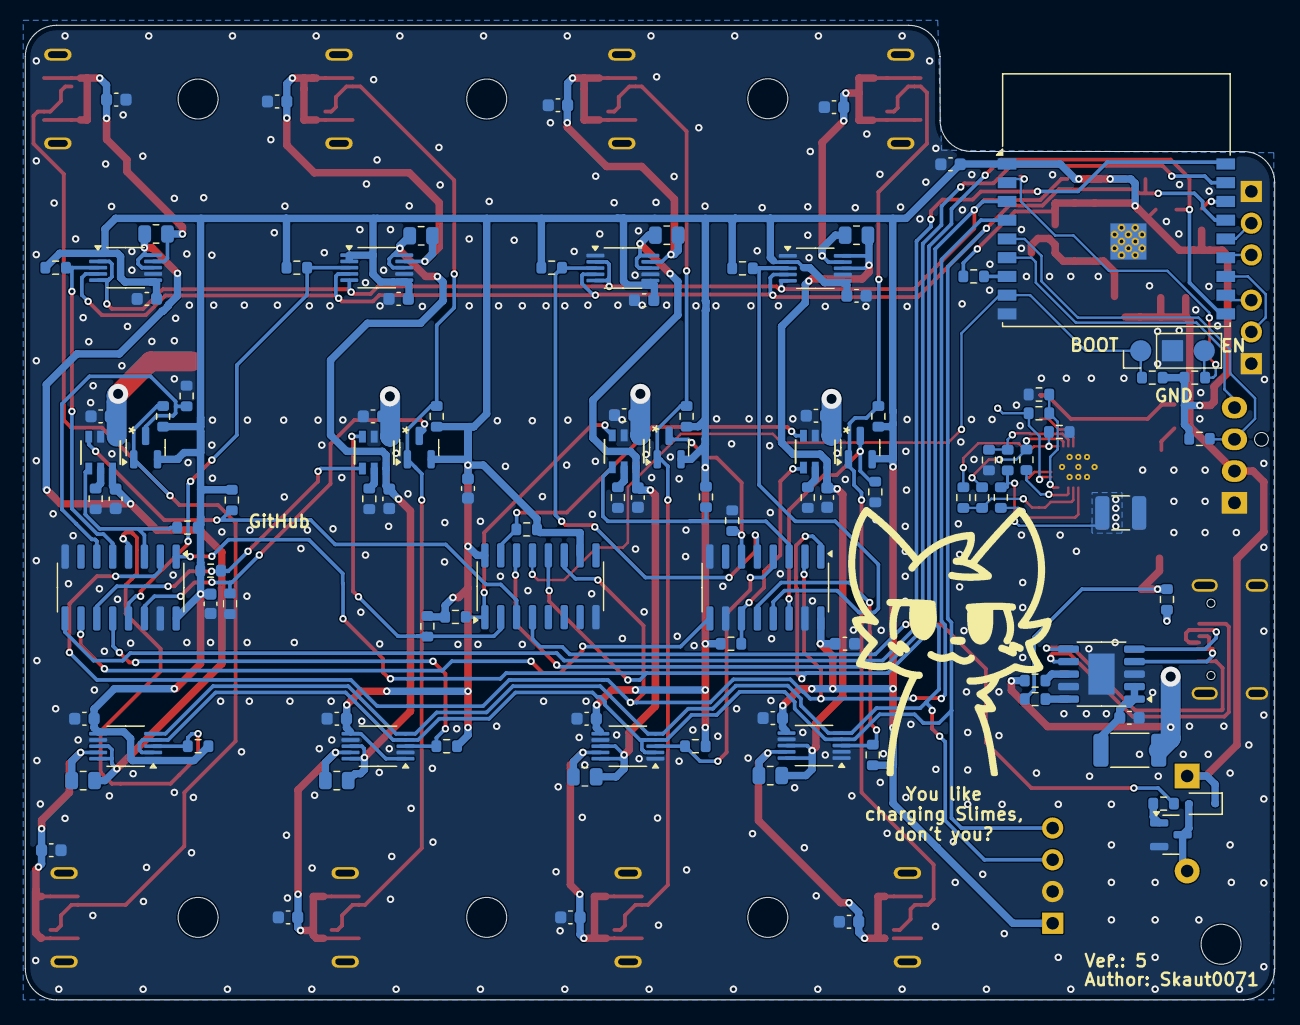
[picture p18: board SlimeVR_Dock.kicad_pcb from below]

Board: 2 copper layers, 100.0 x 78.0 mm, 154 parts (108 on the bottom side), 84 nets.

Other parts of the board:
3V3, 5V: TestPoint_Pad_1.5x1.5mm
USB: TestPoint_Pad_1.5x1.5mm

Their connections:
5VStepDown: 5V.1; also elsewhere on the board
+3V3: 3V3.1; also elsewhere on the board

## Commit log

2026-01-09 Init and pd
    created repositary nad created basic schema with conected power delivery
    [SlimeVR_Dock.kicad_pcb, SlimeVR_Dock.kicad_sch]
2026-01-10 Moved files
    from /board/slimevr_dock/ to /board/
    [SlimeVR_Dock.kicad_pcb, SlimeVR_Dock.kicad_sch]
2026-01-10 made subschema for usb-c
    subschea for USB-Cs for more comact schema
    [DUSBSS.kicad_sch, SlimeVR_Dock.kicad_sch]
2026-01-10 New Layout and power
    Made power for 3v3
    all usb added
    [DUSBSS.kicad_sch, SlimeVR_Dock.kicad_sch, USB-C.kicad_sch]
2026-01-11 Saving pins
    -4 pins to connect to gpio thanks for ability to use two or more alert pins on one gpio
    [DUSBSS.kicad_sch, SlimeVR_Dock.kicad_sch, USB-C.kicad_sch]
2026-01-15 Conecting usb to esp
    added in/out and out/in reistry
    [DUSBSS.kicad_sch, SlimeVR_Dock.kicad_sch, USB-C.kicad_sch]
2026-01-16 Finished Schematic
    [DUSBSS.kicad_sch, SlimeVR_Dock.kicad_pcb, SlimeVR_Dock.kicad_sch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]
2026-01-25 Updavení USB-C
    [SlimeVR_Dock.kicad_pcb, SlimeVR_Dock.kicad_sch, USB-C.kicad_sch]
2026-04-05 layout
    -bude asi potreba jiny footrpint usb-c
    [SlimeVR_Dock.kicad_pcb]
2026-04-07 Custom StepDown
    [SlimeVR_Dock.kicad_sch, StepDown.kicad_sch]
2026-04-07 minority upravy
    [SlimeVR_Dock.kicad_pcb, SlimeVR_Dock.kicad_sch, StepDown.kicad_sch]
2026-04-08 pcb layout
    [SlimeVR_Dock.kicad_pcb, SlimeVR_Dock.kicad_sch]
2026-04-09 upraveni veliskoti
    [SlimeVR_Dock.kicad_pcb, SlimeVR_Dock.kicad_sch]
2026-04-09 prvni segment usb-c
    [SlimeVR_Dock.kicad_pcb]
2026-04-09 pokus o posunutí cívky
    [SlimeVR_Dock.kicad_pcb]
2026-04-09 almost finished layout V1
    [SlimeVR_Dock.kicad_pcb]
2026-04-10 leyout finished
    - needs silkscreen modification
    - usb-c footprint
    [SlimeVR_Dock.kicad_pcb]
2026-04-10 Complete
    -fixed tach pullup missing
    - may have some unrecognised issues
    [SlimeVR_Dock.kicad_pcb, SlimeVR_Dock.kicad_sch, USB-C.kicad_sch]
2026-04-11 Small changes
    [SlimeVR_Dock.kicad_pcb]
2026-04-11 fixed chema, finished silkscreen
    -Alert10 was duplicated
    [SlimeVR_Dock.kicad_pcb, SlimeVR_Dock.kicad_sch]
2026-04-11 Updated fields for LCSC
    [DUSBSS.kicad_sch, SlimeVR_Dock.kicad_pcb, SlimeVR_Dock.kicad_sch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]
2026-04-11 Created greb
    [SlimeVR_Dock-B_Cu.gbr, SlimeVR_Dock-B_Mask.gbr, SlimeVR_Dock-B_Paste.gbr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]
2026-04-11 updated bom
2026-04-17 new pdf schema
    [SlimeVR_Dock.kicad_sch]
2026-05-10 Version 2
    - Fixed StepDown stabilization 5V output - probebly idk :D
    [SlimeVR_Dock.kicad_pcb, StepDown.kicad_sch]
2026-05-10 Fix Layout
    [SlimeVR_Dock.kicad_pcb]
2026-05-11 Fixed CC_detect transistor
    [DUSBSS.kicad_sch, SlimeVR_Dock.kicad_pcb]
2026-05-11 fixed grounding and updated to kicad 10
    [SlimeVR_Dock.kicad_pcb]
2026-05-11 DRC fix
    [SlimeVR_Dock.kicad_pcb]
2026-05-15 Update ibom
    [SlimeVR_Dock-B_Cu.gbr, SlimeVR_Dock-B_Silkscreen.gbr, SlimeVR_Dock-Edge_Cuts.gbr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]
2026-05-16 Total Power Suply layout overhall
    [DUSBSS.kicad_sch, SlimeVR_Dock.kicad_pcb, SlimeVR_Dock.kicad_sch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]
2026-05-16 New Power
    [SlimeVR_Dock.kicad_pcb, SlimeVR_Dock.kicad_sch, StepDown.kicad_sch]
2026-05-16 Fixed zener diode orientation
    [SlimeVR_Dock.kicad_pcb, StepDown.kicad_sch]
2026-05-16 Version 3
    Hopefully it works idk ?:D
    [DUSBSS.kicad_sch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]
2026-05-16 Ground plane edits
    [SlimeVR_Dock.GBL, SlimeVR_Dock.GBO, SlimeVR_Dock.GBP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]
2026-05-17 RC on coil outut and VDD resistor added
    [SlimeVR_Dock.GBL, SlimeVR_Dock.GBO, SlimeVR_Dock.GBP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]
2026-05-17 edited silkscreen
    [SlimeVR_Dock.GBL, SlimeVR_Dock.GBO, SlimeVR_Dock.GBP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]
2026-05-17 fixed pad
    [SlimeVR_Dock.GBL, SlimeVR_Dock.GBO, SlimeVR_Dock.GBP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]
2026-05-17 Changed baed on sugestions
    [SlimeVR_Dock.GBL, SlimeVR_Dock.GBO, SlimeVR_Dock.GBP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]
2026-05-17 added caps to outputs
    [SlimeVR_Dock.GBL, SlimeVR_Dock.GBO, SlimeVR_Dock.GBP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]
2026-05-17 updated by sugestions
    [SlimeVR_Dock.GBL, SlimeVR_Dock.GBO, SlimeVR_Dock.GBP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]
2026-05-17 fixed via in pad
    [SlimeVR_Dock.GBL, SlimeVR_Dock.GBO, SlimeVR_Dock.GBP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]
2026-05-17 caps reorangement
    [SlimeVR_Dock.kicad_pcb]
2026-05-17 fix silkscreen
    [SlimeVR_Dock.kicad_pcb]
2026-05-20 Updated documentation
    [DUSBSS.kicad_sch, SlimeVR_Dock.kicad_pcb, StepDown.kicad_sch]
2026-08-10 Fixing from Review
    [DUSBSS.kicad_sch, SlimeVR_Dock.kicad_sch, StepDown.kicad_sch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]
2026-08-28 open findings are fixed, and nothing else changed
    [StepDown.kicad_sch]
2026-08-28 V4 review update
    - new review from from this version alreaady done
    [DUSBSS.kicad_sch, SlimeVR_Dock.kicad_pcb, SlimeVR_Dock.kicad_sch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]
2026-08-28 more checking and added detailed review
    [DUSBSS.kicad_sch, SlimeVR_Dock.kicad_pcb]
2026-08-28 Small updates from review
    - Updated Revisions
    [DUSBSS.kicad_sch, SlimeVR_Dock.kicad_pcb, SlimeVR_Dock.kicad_sch]
2026-08-29 Updated Inductor for Isat > 17A
    [SlimeVR_Dock.kicad_pcb, StepDown.kicad_sch]
2026-09-20 Board and schema update
    curent mesuring resistors swap for bigger
    some more grounding was done
    [SlimeVR_Dock.kicad_pcb, StepDown.kicad_sch, USB-C.kicad_sch]
2026-09-21 New review completed version
    -Board ONLY changes no documentation updated YET
    [DUSBSS.kicad_sch, SlimeVR_Dock.kicad_pcb, SlimeVR_Dock.kicad_sch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]
2026-09-21 Update dokumentace
    [SlimeVR_Dock.kicad_pcb]
2026-09-21 Updates LCSC codes
    [SlimeVR_Dock.kicad_pcb, StepDown.kicad_sch]
2026-09-21 Some traces angle changes and all LCSC codes added
    [DUSBSS.kicad_sch, SlimeVR_Dock.kicad_pcb, SlimeVR_Dock.kicad_sch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]
2026-09-21 Fixed QR code
    [SlimeVR_Dock.kicad_pcb]
2026-09-21 found correct LCSC code for 14.3k
    [DUSBSS.kicad_sch, SlimeVR_Dock.kicad_pcb]
2026-09-23 ReadMe Update
    [SlimeVR_Dock.kicad_pcb]
2026-09-23 Updated 3D models of components
    [SlimeVR_Dock.kicad_pcb]
2026-09-25 updated diod footprint
    [SlimeVR_Dock.kicad_pcb, SlimeVR_Dock.kicad_sch, USB-C.kicad_sch]
2026-10-01 Final check
    [DUSBSS.kicad_sch, SlimeVR_Dock.kicad_pcb, SlimeVR_Dock.kicad_sch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]
2026-10-01 removed unused files
    [SlimeVR_Dock.kicad_sch, SlimeVR_Dock_bom.csv, StepDown.kicad_sch]

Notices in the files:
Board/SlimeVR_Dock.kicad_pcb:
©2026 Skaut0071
